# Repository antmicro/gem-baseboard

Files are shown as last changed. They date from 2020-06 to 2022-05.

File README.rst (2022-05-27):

GEM Demo Board
==============

Copyright (c) 2020 `Antmicro <https://www.antmicro.com>`_


   
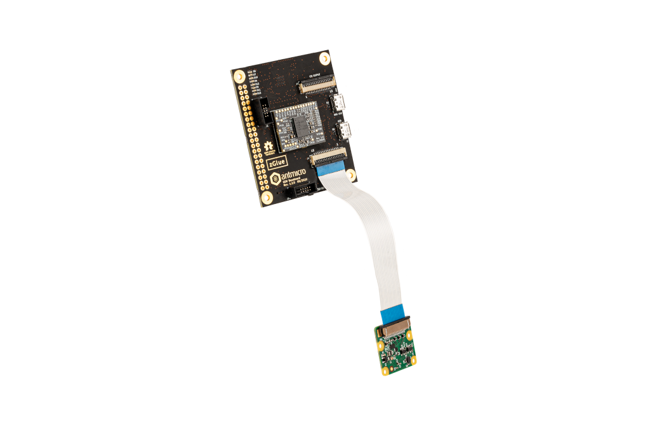
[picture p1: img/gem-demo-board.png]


This repository contains PCB design files for a demo board compatible with the `GEM1 <https://github.com/antmicro/gem1-adapter>`_ and `GEM2 <https://github.com/antmicro/gem2-adapter>`_ adapter boards.

The board acts as an evaluation carrier board for the GEM adapter boards.
It includes a 4-channel FTDI USB/MPSSE converter that can be used for configuring the chiplets inside the GEM designs from an external host PC using a single USB connection and the MPSSE engine built into the FTDI controller.

The board contains two FFC connectors supporting MIPI CSI input and output.
The FFC connectors are pin-compatible with the Raspberry Pi camera interface.
It is possible to connect a Raspberry Pi camera module to the input connector on the board and provide processed CSI data back on the output CSI FFC.
It is also possible to configure the board as an expansion hat for the Raspberry Pi platform.
For more details regarding the supported connection scenarios please refer to the respective schematic sheets.

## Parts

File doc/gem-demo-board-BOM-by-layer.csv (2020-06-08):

Reference | Quantity | Value | Footprint | Manufacturer | MPN | Layer
D10 D11 D12 D13 D6 D7 D8 D9 | 8 | LG_L29K-G2J1-24-Z | LED_0603 | OSRAM Opto Semiconductors Inc. | LG L29K-G2J1-24-Z | Top
D2 D5 | 2 | TPD2EUSB30DRTR | SOT-3 | Texas Instruments | TPD2EUSB30DRTR | Top
J1 J3 | 2 | 3220-10-0100-00 | PinHeader_2x5_P1.27mm_Drill.7mm | CNC Tech | 3220-10-0100-00 | Top
J10 J5 | 2 | 0473460001 | USB_Micro_B_Female_0473460001 | Molex | 0473460001 | Top
J6 J7 | 2 | 556500488 | 556500488 | Molex | 556500488 | Top
J8 J9 | 2 | WE_686115148922_FLIPPED | WE_686115148922_FLIPPED | Wurth Elektronik | 686115148922 | Top
C1 C2 C3 C4 C5 | 5 | C_1u_0603 | 0603-cap | WALSIN | 0603X105K160CT | Bottom
C10 C11 C12 C13 C14 C15 C16 C17 C18 C19 C20 C21 C22 C23 C24 C9 | 16 | C_100n_0402_6V3 | 0402-cap | Walsin | 0402X104K6R3CT | Bottom
C25 C26 | 2 | C_4u7_0402 | 0402-cap | MURATA | GRM155R60G475ME | Bottom
D1 D3 D4 | 3 | MBR0540T1G | SOD-123 | ON Semiconductor | MBR0540T1G | Bottom
FB1 FB2 | 2 | BLM18AG601SN1D | 0603 | Murata Electronics North America | BLM18AG601SN1D | Bottom
J2 | 1 | DF13A-2P-1.25H | DF13A-2P-1.25H | Hirose | DF13A-2P-1.25H | Bottom
J4 | 1 | 2x20_Header_Female | PinHeader_2x40_P2.54_Drill1mm | MULTICOMP | 2214S-40SG-85 | Bottom
R1 | 1 | R_0R_0603 | 0603-res | BOURNS | CR0603-J/-000ELF | Bottom
R10 R5 | 2 | R_2k_0402 | 0402-res | VISHAY | CRCW04022K00FKED | Bottom
R11 R12 R13 R14 R15 R16 R17 R18 R19 R2 R20 R21 R22 R23 R24 R25 R26 R27 R28 R29 R3 R30 R31 R32 R33 R42 R43 R48 R49 R58 R59 R60 R8 | 33 | R_0R_0402 | 0402-res | PANASONIC | ERJ2GE0R00X | Bottom
R34 | 1 | R_470R_0402 | 0402-res | VISHAY | CRCW0402470RFKED. | Bottom
R35 R36 R37 R38 R39 R40 R41 | 7 | R_330R_0402 | 0402-res | MULTICOMP | MCMR04X3300FTL | Bottom
R4 R6 R7 | 3 | R_10k_0402 | 0402-res | VISHAY | CRCW040210K0FKEDHP | Bottom
R61 | 1 | R_220R_0402 | 0402-res | TE_CONNECTIVITY_/_NEOHM | CRG0402J220R | Bottom
R9 | 1 | R_12k_0402 | 0402-res | VISHAY | CRCW040212K0FKEDHP | Bottom
S1 | 1 | EVQPUA02K | Panasonic_EVQPUJ_EVQPUA | Panasonic | EVQPUA02K | Bottom
U1 | 1 | MCP1700T-3302E_TT | SOT-23-3 | Microchip Technology | MCP1700T-3302E/TT | Bottom
U2 U3 U4 | 3 | NTS0104BQ | QDHVQFN14 | NXP Semiconductors | NTS0104BQ | Bottom
U5 | 1 | 93LC56CT-IMC | DFN-8_2x3mm | Microchip | 93LC56CT-I/MC | Bottom
U6 | 1 | FT4232HQ | FT4232HQ | FTDI | FT4232HQ | Bottom
U7 U8 | 2 | NTB0104BQ | QDHVQFN14 | NXP Semiconductors | NTB0104BQ | Bottom
Y1 | 1 | ASFLMB-12.000MHZ-LC-T | ASFLMB | TXC | ASFLMB-12.000MHZ-LC-T | Bottom
R44 R45 R46 R47 R50 R51 R52 R53 R54 R55 R56 R57 | 12 | R_0R_0402 | 0402-res | PANASONIC | ERJ2GE0R00X | DNP
N2 | 1 | zglue_logo | zglue-logo |  |  | Virtual
N3 | 1 | oshw_logo | oshw-logo |  |  | Virtual
TP1 TP10 TP11 TP12 TP13 TP14 TP15 TP16 TP17 TP18 TP19 TP2 TP20 TP21 TP22 TP23 TP3 TP4 TP5 TP6 TP7 TP8 TP9 | 23 | TP_SMD1MM | Testpoint_smd_1mm |  |  | Virtual
VCCIO1 VCCIO2 VCCIO3 | 3 | Jumper_3_Open-Jumper |  |  |  | Virtual

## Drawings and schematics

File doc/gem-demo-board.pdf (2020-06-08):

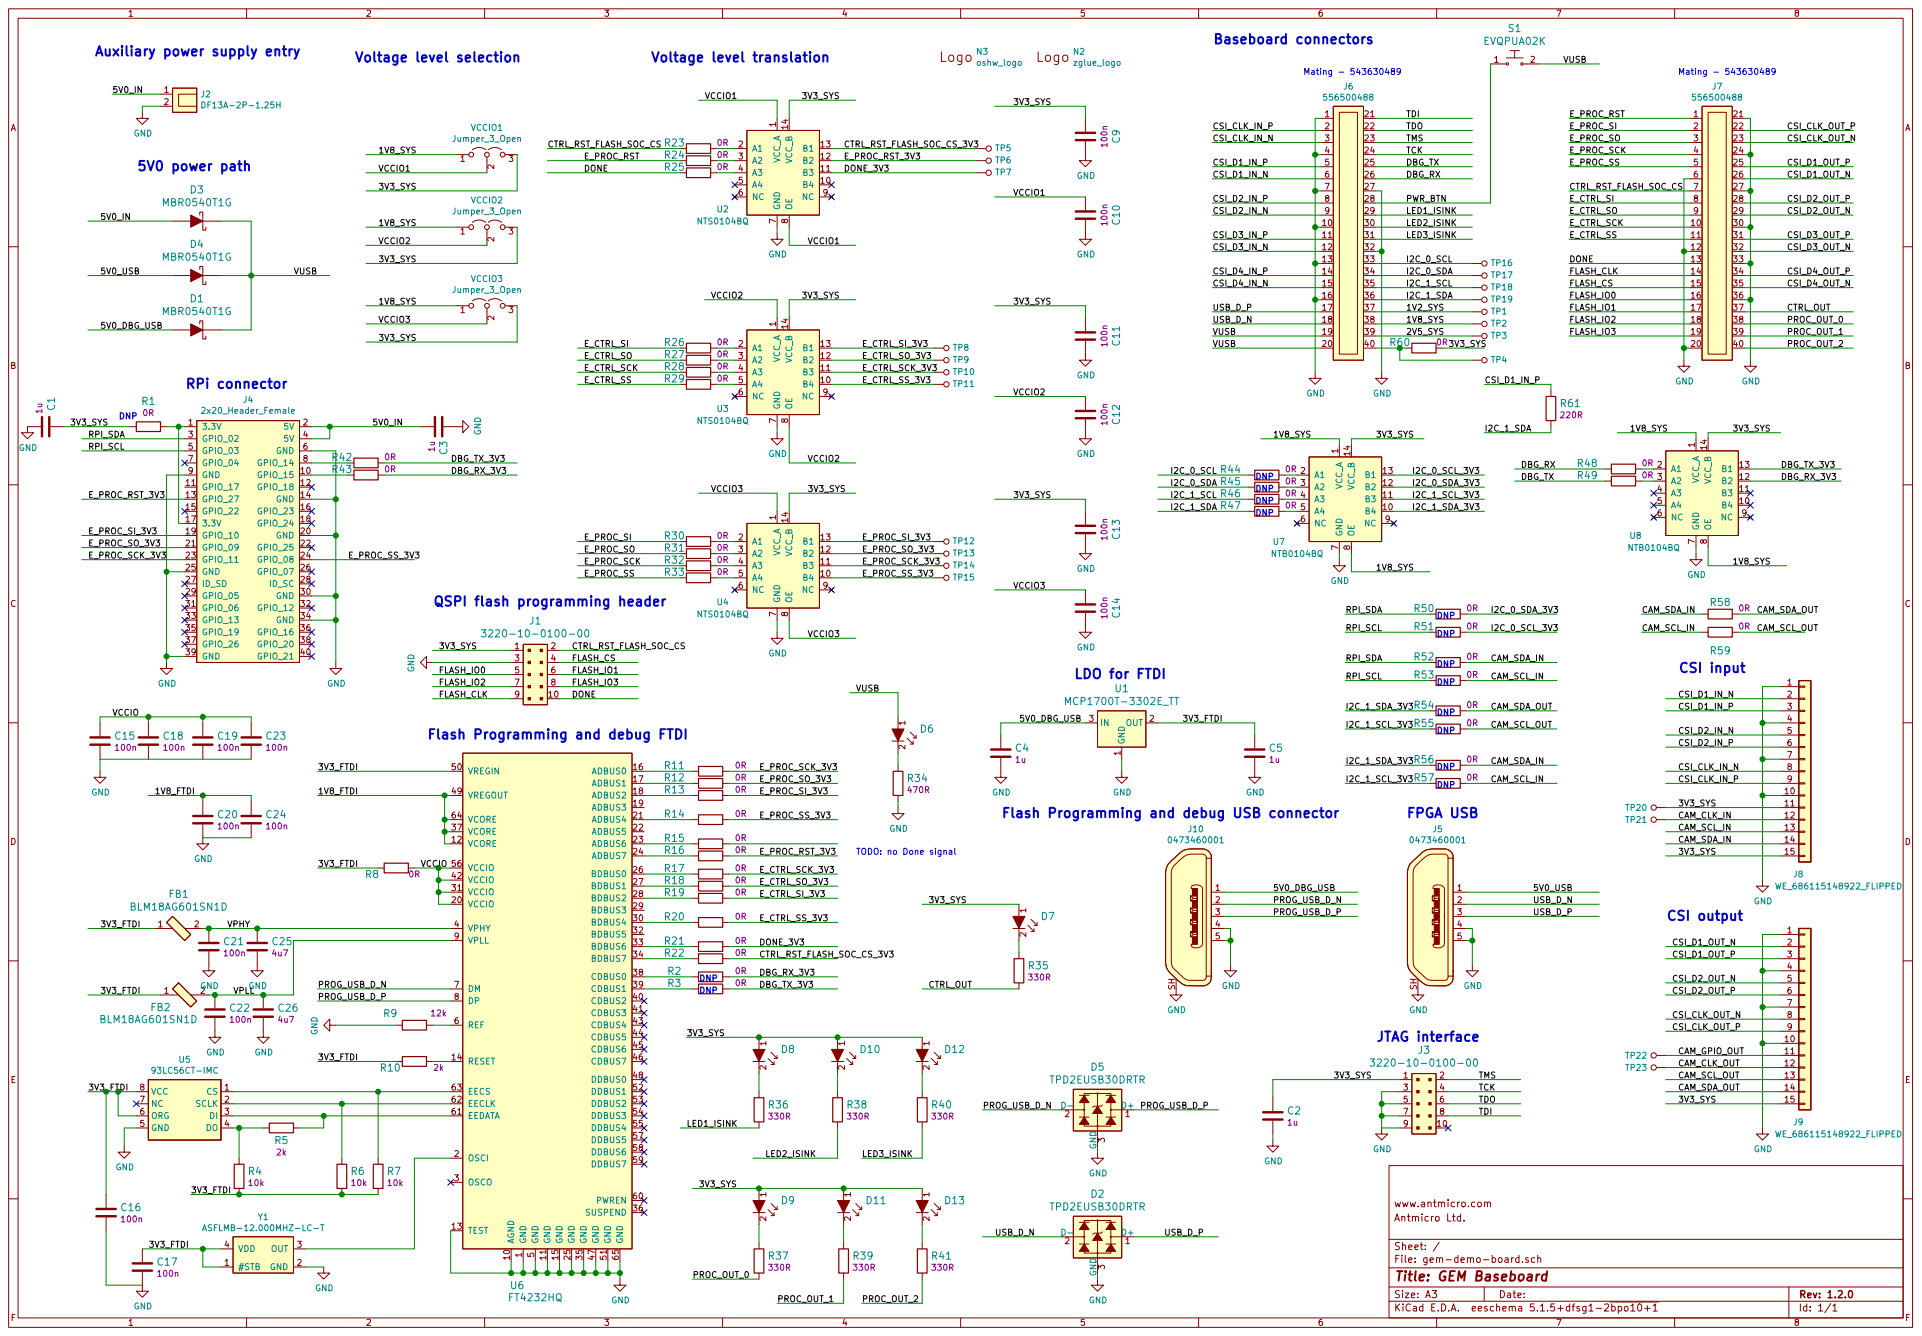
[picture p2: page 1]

Auxiliary power supply entry

23 TMS | E_PROC_SI CSI_D1_IN_N E_PROC_SO 3

22 TDO | 2

24 TCK | E_PROC_SCK 4
25 | E_PROC_SS 5
26 | 6

QSPI flash programming header

Flash Programming and debug FTDI

1 AGND 10 GND 11 VCORE 12 TEST 13 RESET 14 GND 15 ADBUS0 16 ADBUS1 17 ADBUS2 18 ADBUS3 19 OSCI 2 VCCIO 20 ADBUS4 21 ADBUS5 22 ADBUS6 23 ADBUS7 24 GND 25 BDBUS0 26 BDBUS1 27 BDBUS2 28 BDBUS3 29 OSCO 3 BDBUS4 30 VCCIO 31 BDBUS5 32 BDBUS6 33 BDBUS7 34 GND 35 SUSPEND 36 VCORE 37 CDBUS0 38 CDBUS1 39 VPHY 4 CDBUS2 40 CDBUS3 41 VCCIO 42 CDBUS4 43 CDBUS5 44 CDBUS6 45 CDBUS7 46 GND 47 DDBUS0 48 VREGOUT 49 GND

5 VREGIN 50 GND 51 DDBUS1 52 DDBUS2 53 DDBUS3 54 DDBUS4 55 VCCIO 56 DDBUS5 57 DDBUS6 58 DDBUS7 59 REF 6 PWREN 60 EEDATA 61 EECLK 62 EECS 63 VCORE 64 GND 65 DM 7 DP 8 VPLL 9 U6 FT4232HQ

Flash Programming and debug USB connector

TODO: no Done signal

File: gem-demo-board.sch Sheet: / Antmicro Ltd. www.antmicro.com

Id: 1/1 Title: GEM Baseboard

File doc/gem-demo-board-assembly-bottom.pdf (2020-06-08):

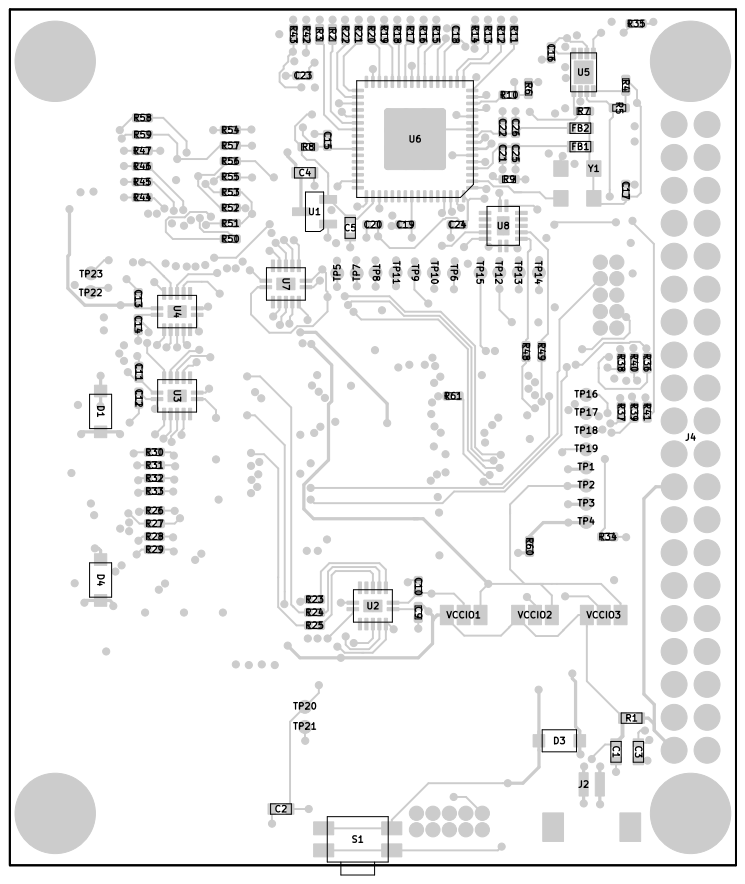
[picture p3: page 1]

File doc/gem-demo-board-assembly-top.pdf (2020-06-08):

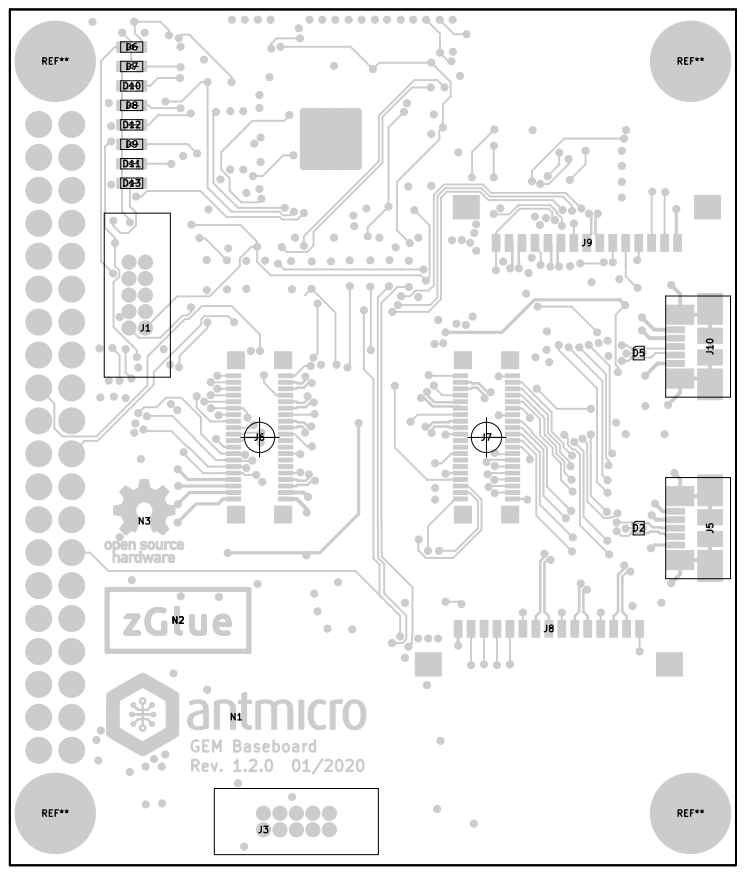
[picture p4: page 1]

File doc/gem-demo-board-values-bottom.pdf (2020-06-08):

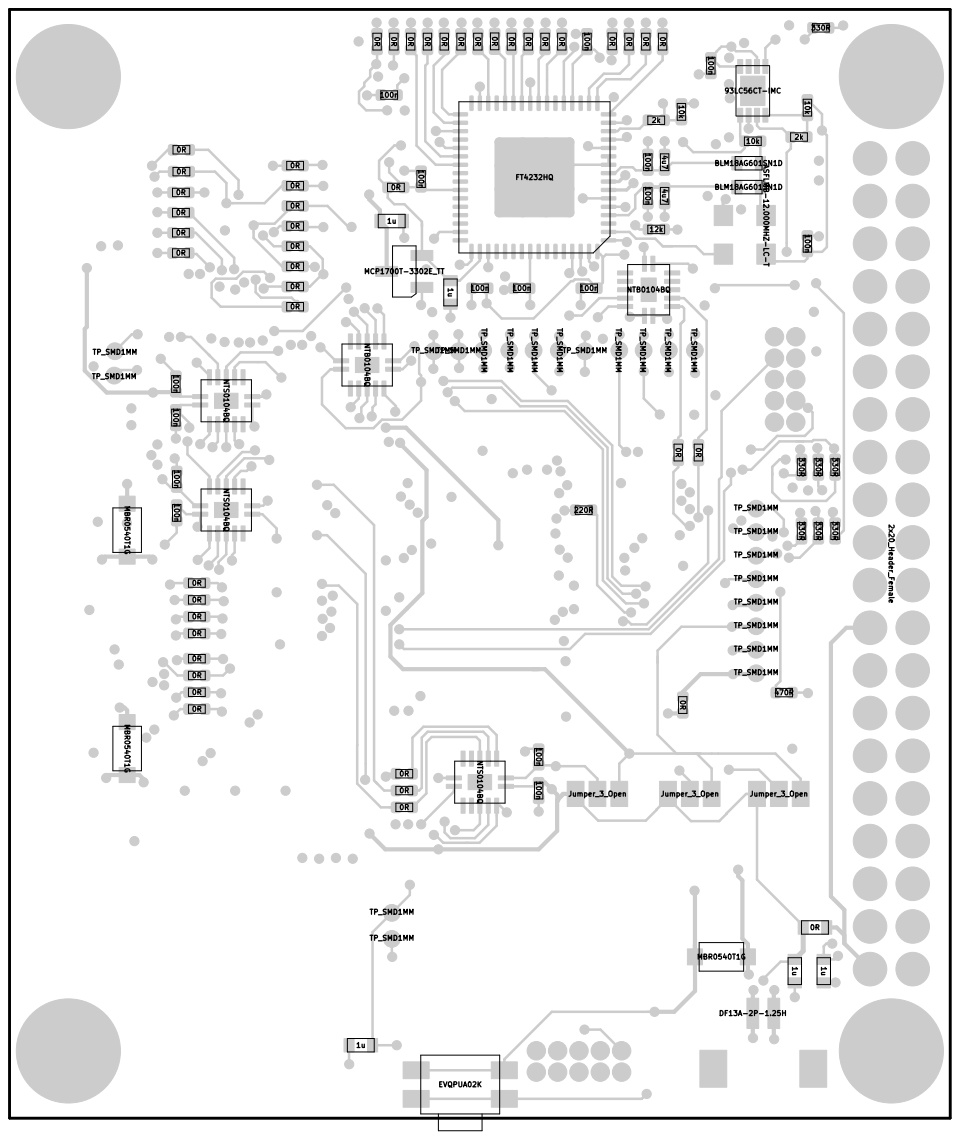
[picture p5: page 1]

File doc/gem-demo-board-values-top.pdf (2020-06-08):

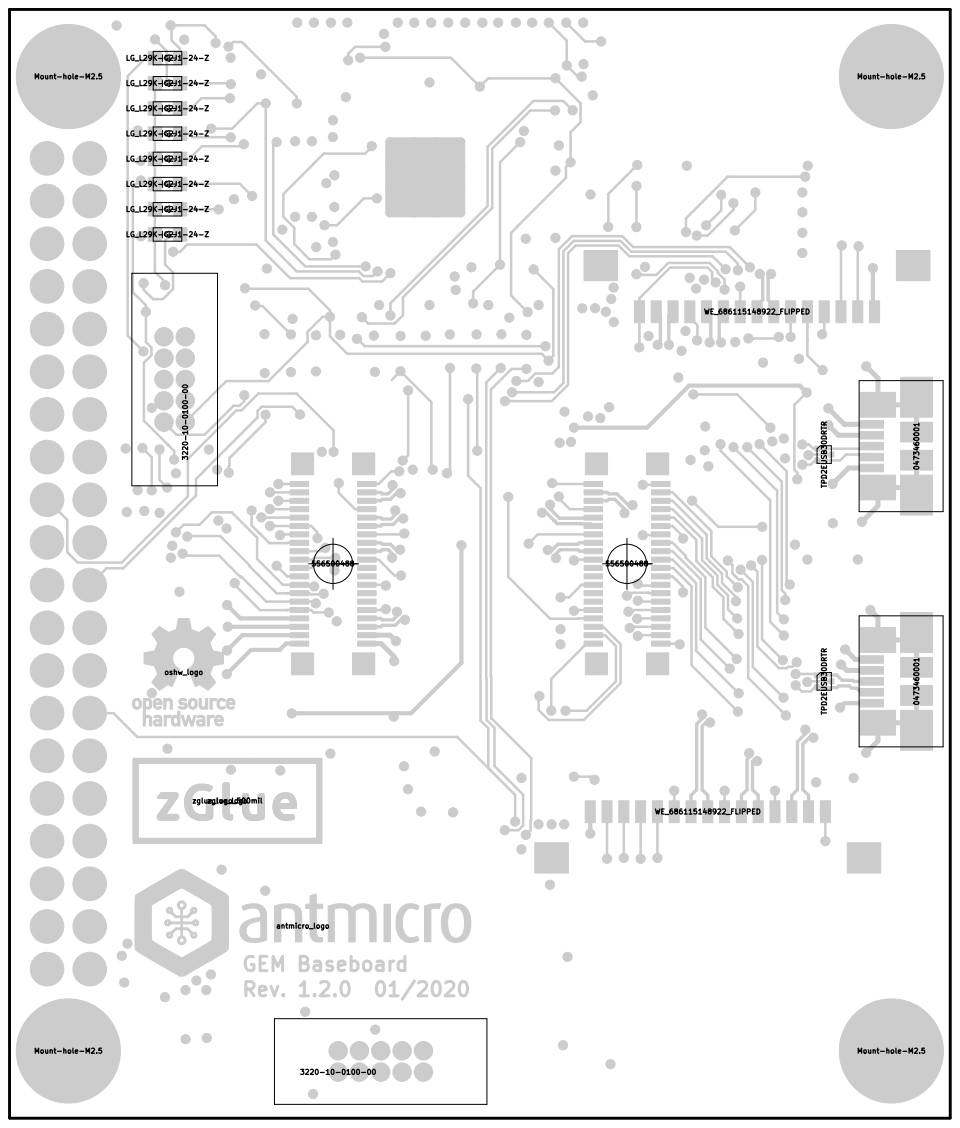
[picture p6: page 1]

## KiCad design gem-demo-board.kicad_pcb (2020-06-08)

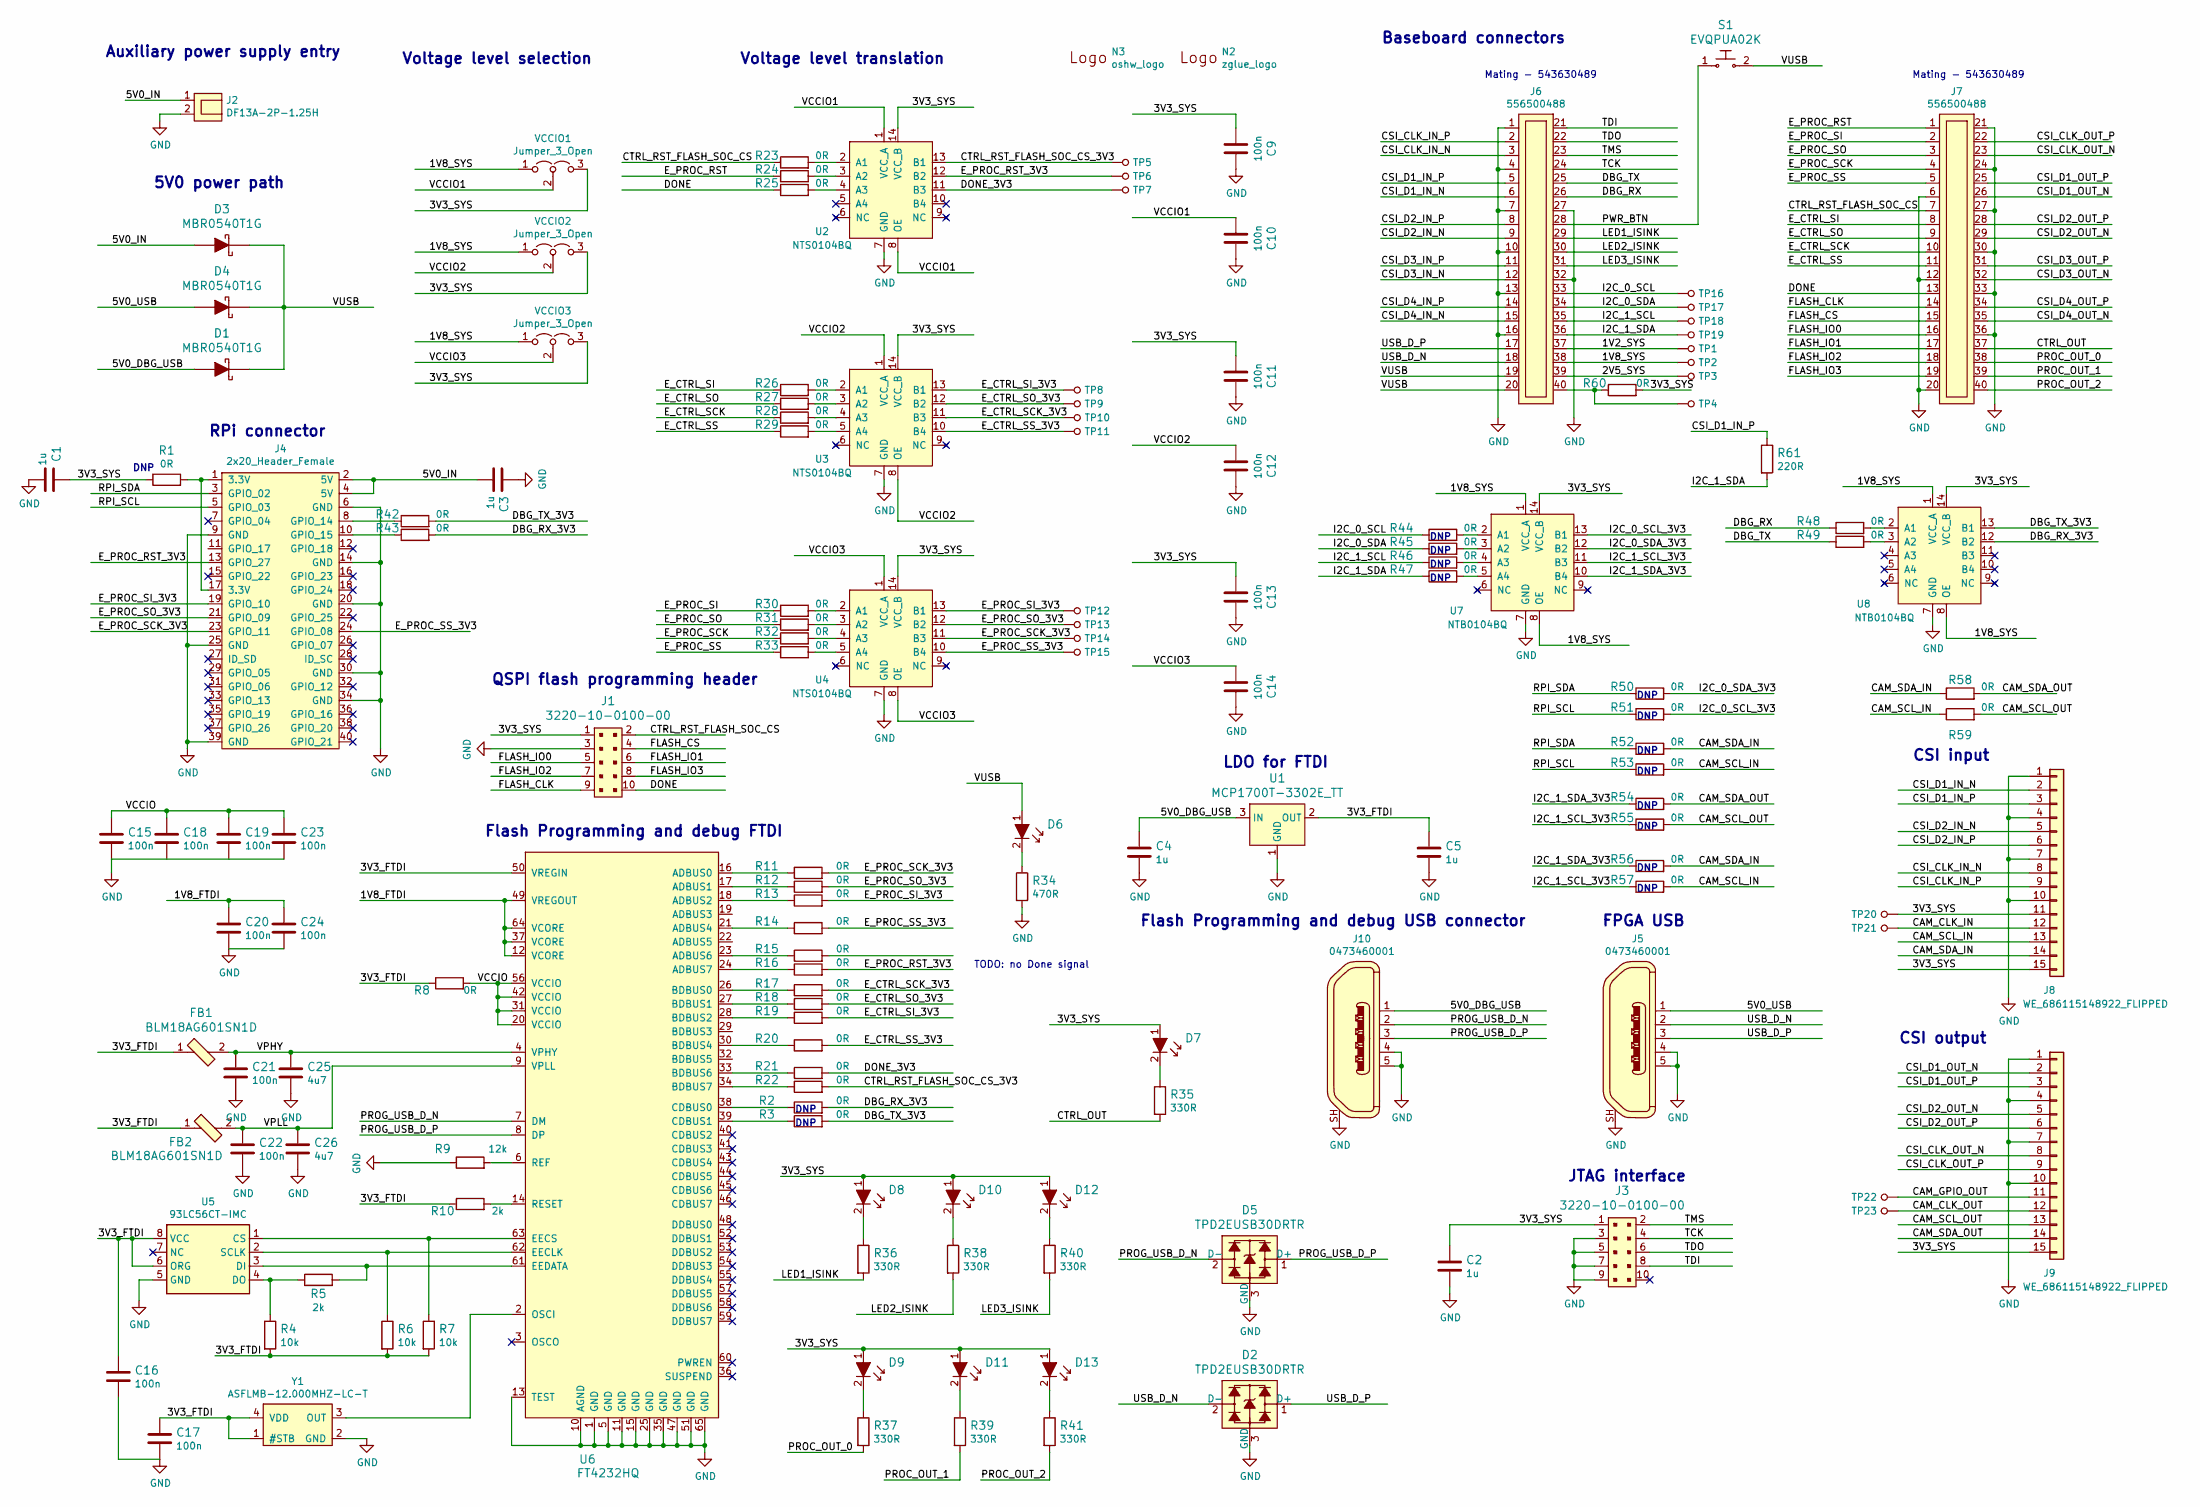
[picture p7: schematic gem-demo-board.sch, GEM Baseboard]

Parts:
C1, C2, C3, C4, C5: C_1u_0603; 0603-cap; MPN 0603X105K160CT
C9, C10, C11, C12, C13, C14, C15, C16, C17, C18, C19, C20, C21, C22, C23, C24: C_100n_0402_6V3; 0402-cap; MPN 0402X104K6R3CT
C25, C26: C_4u7_0402; 0402-cap; MPN GRM155R60G475ME
D1, D3, D4: MBR0540T1G; SOD-123; MPN MBR0540T1G
D2, D5: TPD2EUSB30DRTR; SOT-3; MPN TPD2EUSB30DRTR
D6, D7, D8, D9, D10, D11, D12, D13: LG_L29K-G2J1-24-Z; LED_0603; MPN LG L29K-G2J1-24-Z
FB1, FB2: BLM18AG601SN1D; 0603; MPN BLM18AG601SN1D
J1, J3: 3220-10-0100-00; PinHeader_2x5_P1.27mm_Drill.7mm; MPN 3220-10-0100-00
J2: DF13A-2P-1.25H; MPN DF13A-2P-1.25H
J4: 2x20_Header_Female; PinHeader_2x40_P2.54_Drill1mm; MPN 2214S-40SG-85
J5, J10: 0473460001; USB_Micro_B_Female_0473460001; MPN 0473460001
J6, J7: 556500488; MPN 556500488
J8, J9: WE_686115148922_FLIPPED; MPN 686115148922
N2: zglue_logo; zglue-logo
N3: oshw_logo; oshw-logo
R1: R_0R_0603; 0603-res; MPN CR0603-J/-000ELF
R2, R3, R8, R11, R12, R13, R14, R15, R16, R17, R18, R19, R20, R21, R22, R23, R24, R25, R26, R27, R28, R29, R30, R31, R32, R33, R42, R43, R44, R45, R46, R47, R48, R49, R50, R51, R52, R53, R54, R55, R56, R57, R58, R59, R60: R_0R_0402; 0402-res; MPN ERJ2GE0R00X
R4, R6, R7: R_10k_0402; 0402-res; MPN CRCW040210K0FKEDHP
R5, R10: R_2k_0402; 0402-res; MPN CRCW04022K00FKED
R9: R_12k_0402; 0402-res; MPN CRCW040212K0FKEDHP
R34: R_470R_0402; 0402-res; MPN CRCW0402470RFKED.
R35, R36, R37, R38, R39, R40, R41: R_330R_0402; 0402-res; MPN MCMR04X3300FTL
R61: R_220R_0402; 0402-res; MPN CRG0402J220R
S1: EVQPUA02K; Panasonic_EVQPUJ_EVQPUA; MPN EVQPUA02K
TP1, TP2, TP3, TP4, TP5, TP6, TP7, TP8, TP9, TP10, TP11, TP12, TP13, TP14, TP15, TP16, TP17, TP18, TP19, TP20, TP21, TP22, TP23: TP_SMD1MM; Testpoint_smd_1mm
U1: MCP1700T-3302E_TT; SOT-23-3; MPN MCP1700T-3302E/TT
U2, U3, U4: NTS0104BQ; QDHVQFN14; MPN NTS0104BQ
U5: 93LC56CT-IMC; DFN-8_2x3mm; MPN 93LC56CT-I/MC
U6: FT4232HQ; MPN FT4232HQ
U7, U8: NTB0104BQ; QDHVQFN14; MPN NTB0104BQ
VCCIO1, VCCIO2, VCCIO3: Jumper_3_Open; SolderJumper-3_P1.3mm_Open_Pad1.0x1.5mm
Y1: ASFLMB-12.000MHZ-LC-T; ASFLMB; MPN ASFLMB-12.000MHZ-LC-T

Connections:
/1V2_SYS: J6.37, TP1.1
/1V8_FTDI: C20.1, C24.1, U6.12 (VCORE), U6.37 (VCORE), U6.49 (VREGOUT), U6.64 (VCORE)
/1V8_SYS: J6.38, TP2.1, U7.1 (VCC_A), U7.8 (OE), U8.1 (VCC_A), U8.8 (OE), VCCIO1.1 (A), VCCIO2.1 (A), VCCIO3.1 (A)
/2V5_SYS: J6.39, TP3.1
/3V3_FTDI: C5.1, C16.1, C17.1, FB1.1, FB2.1, R4.2, R6.2, R7.2, R8.1, R10.1, U1.2 (OUT), U5.6 (ORG), U5.8 (VCC), U6.50 (VREGIN), Y1.1 (#STB), Y1.4 (VDD)
/3V3_SYS: C1.1, C2.1, C9.2, C11.2, C13.2, D7.1, D8.1, D9.1, D10.1, D11.1, D12.1, D13.1, J1.1, J3.1, J8.11, J8.15, J9.15, R1.1, R60.2, TP20.1, U2.14 (VCC_B), U3.14 (VCC_B), U4.14 (VCC_B), U7.14 (VCC_B), U8.14 (VCC_B), VCCIO1.3 (B), VCCIO2.3 (B), VCCIO3.3 (B)
/5V0_DBG_USB: C4.1, D1.A, J10.1, U1.3 (IN)
/5V0_IN: C3.2, D3.A, J2.1, J4.2 (5V), J4.4 (5V)
/5V0_USB: D4.A, J5.1
/CAM_CLK_IN: J8.12, TP21.1
/CAM_CLK_OUT: J9.12, TP23.1
/CAM_GPIO_OUT: J9.11, TP22.1
/CAM_SCL_IN: J8.13, R53.2, R57.2, R59.1
/CAM_SCL_OUT: J9.13, R55.2, R59.2
/CAM_SDA_IN: J8.14, R52.2, R56.2, R58.1
/CAM_SDA_OUT: J9.14, R54.2, R58.2
/CSI_CLK_IN_N: J6.3, J8.8
/CSI_CLK_IN_P: J6.2, J8.9
/CSI_CLK_OUT_N: J7.23, J9.8
/CSI_CLK_OUT_P: J7.22, J9.9
/CSI_D1_IN_N: J6.6, J8.2
/CSI_D1_IN_P: J6.5, J8.3, R61.1
/CSI_D1_OUT_N: J7.26, J9.2
/CSI_D1_OUT_P: J7.25, J9.3
/CSI_D2_IN_N: J6.9, J8.5
/CSI_D2_IN_P: J6.8, J8.6
/CSI_D2_OUT_N: J7.29, J9.5
/CSI_D2_OUT_P: J7.28, J9.6
/CSI_D3_IN_N: J6.12
/CSI_D3_IN_P: J6.11
/CSI_D3_OUT_N: J7.32
/CSI_D3_OUT_P: J7.31
/CSI_D4_IN_N: J6.15
/CSI_D4_IN_P: J6.14
/CSI_D4_OUT_N: J7.35
/CSI_D4_OUT_P: J7.34
/CTRL_OUT: J7.37, R35.2
/CTRL_RST_FLASH_SOC_CS: J1.2, J7.7, R23.1
/CTRL_RST_FLASH_SOC_CS_3V3: R22.2, TP5.1, U2.13 (B1)
/DBG_RX: J6.26, R48.1
/DBG_RX_3V3: R2.2, R43.2, U8.12 (B2)
/DBG_TX: J6.25, R49.1
/DBG_TX_3V3: R3.2, R42.2, U8.13 (B1)
/DONE: J1.10, J7.13, R25.1
/DONE_3V3: R21.2, TP7.1, U2.11 (B3)
/E_CTRL_SCK: J7.10, R28.1
/E_CTRL_SCK_3V3: R17.2, TP10.1, U3.11 (B3)
/E_CTRL_SI: J7.8, R26.1
/E_CTRL_SI_3V3: R19.2, TP8.1, U3.13 (B1)
/E_CTRL_SO: J7.9, R27.1
/E_CTRL_SO_3V3: R18.2, TP9.1, U3.12 (B2)
/E_CTRL_SS: J7.11, R29.1
/E_CTRL_SS_3V3: R20.2, TP11.1, U3.10 (B4)
/E_PROC_RST: J7.1, R24.1
/E_PROC_RST_3V3: J4.13 (GPIO_27), R16.2, TP6.1, U2.12 (B2)
/E_PROC_SCK: J7.4, R32.1
/E_PROC_SCK_3V3: J4.23 (GPIO_11), R11.2, TP14.1, U4.11 (B3)
/E_PROC_SI: J7.2, R30.1
/E_PROC_SI_3V3: J4.19 (GPIO_10), R13.2, TP12.1, U4.13 (B1)
/E_PROC_SO: J7.3, R31.1
/E_PROC_SO_3V3: J4.21 (GPIO_09), R12.2, TP13.1, U4.12 (B2)
/E_PROC_SS: J7.5, R33.1
/E_PROC_SS_3V3: J4.24 (GPIO_08), R14.2, TP15.1, U4.10 (B4)
/FLASH_CLK: J1.9, J7.14
/FLASH_CS: J1.4, J7.15
/FLASH_IO0: J1.5, J7.16
/FLASH_IO1: J1.6, J7.17
/FLASH_IO2: J1.7, J7.18
/FLASH_IO3: J1.8, J7.19
/I2C_0_SCL: J6.33, R44.1, TP16.1
/I2C_0_SCL_3V3: R51.2, U7.13 (B1)
/I2C_0_SDA: J6.34, R45.1, TP17.1
/I2C_0_SDA_3V3: R50.2, U7.12 (B2)
/I2C_1_SCL: J6.35, R46.1, TP18.1
/I2C_1_SCL_3V3: R55.1, R57.1, U7.11 (B3)
/I2C_1_SDA: J6.36, R47.1, R61.2, TP19.1
/I2C_1_SDA_3V3: R54.1, R56.1, U7.10 (B4)
/LED1_ISINK: J6.29, R36.2
/LED2_ISINK: J6.30, R38.2
/LED3_ISINK: J6.31, R40.2
/PROC_OUT_0: J7.38, R37.2
/PROC_OUT_1: J7.39, R39.2
/PROC_OUT_2: J7.40, R41.2
/PROG_USB_D_N: D5.2 (D-), J10.2, U6.7 (DM)
/PROG_USB_D_P: D5.1 (D+), J10.3, U6.8 (DP)
/PWR_BTN: J6.28, S1.1
/RPI_SCL: J4.5 (GPIO_03), R51.1, R53.1
/RPI_SDA: J4.3 (GPIO_02), R50.1, R52.1
/TCK: J3.4, J6.24
/TDI: J3.8, J6.21
/TDO: J3.6, J6.22
/TMS: J3.2, J6.23
/USB_D_N: D2.2 (D-), J5.2, J6.18
/USB_D_P: D2.1 (D+), J5.3, J6.17
/VCCIO: C15.1, C18.1, C19.1, C23.1, R8.2, U6.20 (VCCIO), U6.31 (VCCIO), U6.42 (VCCIO), U6.56 (VCCIO)
/VCCIO1: C10.2, U2.1 (VCC_A), U2.8 (OE), VCCIO1.2 (C)
/VCCIO2: C12.2, U3.1 (VCC_A), U3.8 (OE), VCCIO2.2 (C)
/VCCIO3: C14.2, U4.1 (VCC_A), U4.8 (OE), VCCIO3.2 (C)
/VPHY: C21.1, C25.1, FB1.2, U6.4 (VPHY)
/VPLL: C22.1, C26.1, FB2.2, U6.9 (VPLL)
/VUSB: D1.K, D3.K, D4.K, D6.1, J6.19, J6.20, S1.2
GND: C1.2, C2.2, C3.1, C4.2, C5.2, C9.1, C10.1, C11.1, C12.1, C13.1, C14.1, C15.2, C16.2, C17.2, C20.2, C21.2, C22.2, C23.2, C24.2, C25.2, C26.2, D2.3 (GND), D5.3 (GND), J1.3, J2.2, J3.3, J3.5, J3.7, J3.9, J4.6 (GND), J4.9 (GND), J4.14 (GND), J4.20 (GND), J4.25 (GND), J4.30 (GND), J4.34 (GND), J4.39 (GND), J5.4, J5.5, J5.SH, J6.1, J6.4, J6.7, J6.10, J6.13, J6.16, J6.27, J6.32, J7.6, J7.12, J7.20, J7.21, J7.24, J7.27, J7.30, J7.33, J7.36, J8.1, J8.4, J8.7, J8.10, J9.1, J9.4, J9.7, J9.10, J10.4, J10.5, J10.SH, R9.1, R34.2, U1.1 (GND), U2.7 (GND), U3.7 (GND), U4.7 (GND), U5.5 (GND), U6.1 (GND), U6.5 (GND), U6.10 (AGND), U6.11 (GND), U6.13 (TEST), U6.15 (GND), U6.25 (GND), U6.35 (GND), U6.47 (GND), U6.51 (GND), U6.65 (GND), U7.7 (GND), U8.7 (GND), Y1.2 (GND)
unnamed: D6.2, R34.1
unnamed: D7.2, R35.1
unnamed: D8.2, R36.1
unnamed: D9.2, R37.1
unnamed: D10.2, R38.1
unnamed: D11.2, R39.1
unnamed: D12.2, R40.1
unnamed: D13.2, R41.1
unnamed: J4.1 (3.3V), J4.17 (3.3V), R1.2
unnamed: J4.8 (GPIO_14), R42.1
unnamed: J4.10 (GPIO_15), R43.1
unnamed: J6.40, R60.1, TP4.1
unnamed: R2.1, U6.38 (CDBUS0)
unnamed: R3.1, U6.39 (CDBUS1)
unnamed: R4.1, R5.1, U5.4 (DO)
unnamed: R5.2, U5.3 (DI), U6.61 (EEDATA)
unnamed: R6.1, U5.2 (SCLK), U6.62 (EECLK)
unnamed: R7.1, U5.1 (CS), U6.63 (EECS)
unnamed: R9.2, U6.6 (REF)
unnamed: R10.2, U6.14 (RESET)
unnamed: R11.1, U6.16 (ADBUS0)
unnamed: R12.1, U6.17 (ADBUS1)
unnamed: R13.1, U6.18 (ADBUS2)
unnamed: R14.1, U6.21 (ADBUS4)
unnamed: R15.1, U6.23 (ADBUS6)
unnamed: R16.1, U6.24 (ADBUS7)
unnamed: R17.1, U6.26 (BDBUS0)
unnamed: R18.1, U6.27 (BDBUS1)
unnamed: R19.1, U6.28 (BDBUS2)
unnamed: R20.1, U6.30 (BDBUS4)
unnamed: R21.1, U6.33 (BDBUS6)
unnamed: R22.1, U6.34 (BDBUS7)
unnamed: R23.2, U2.2 (A1)
unnamed: R24.2, U2.3 (A2)
unnamed: R25.2, U2.4 (A3)
unnamed: R26.2, U3.2 (A1)
unnamed: R27.2, U3.3 (A2)
unnamed: R28.2, U3.4 (A3)
unnamed: R29.2, U3.5 (A4)
unnamed: R30.2, U4.2 (A1)
unnamed: R31.2, U4.3 (A2)
unnamed: R32.2, U4.4 (A3)
unnamed: R33.2, U4.5 (A4)
unnamed: R44.2, U7.2 (A1)
unnamed: R45.2, U7.3 (A2)
unnamed: R46.2, U7.4 (A3)
unnamed: R47.2, U7.5 (A4)
unnamed: R48.2, U8.2 (A1)
unnamed: R49.2, U8.3 (A2)
unnamed: U6.2 (OSCI), Y1.3 (OUT)

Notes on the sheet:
Baseboard connectors
Auxiliary power supply entry
RPi connector
JTAG interface
FPGA USB
5V0 power path
CSI input
CSI output
Mating - 543630489
Voltage level translation
Flash Programming and debug USB connector
Flash Programming and debug FTDI
TODO: no Done signal
LDO for FTDI
Voltage level selection
QSPI flash programming header
DNP

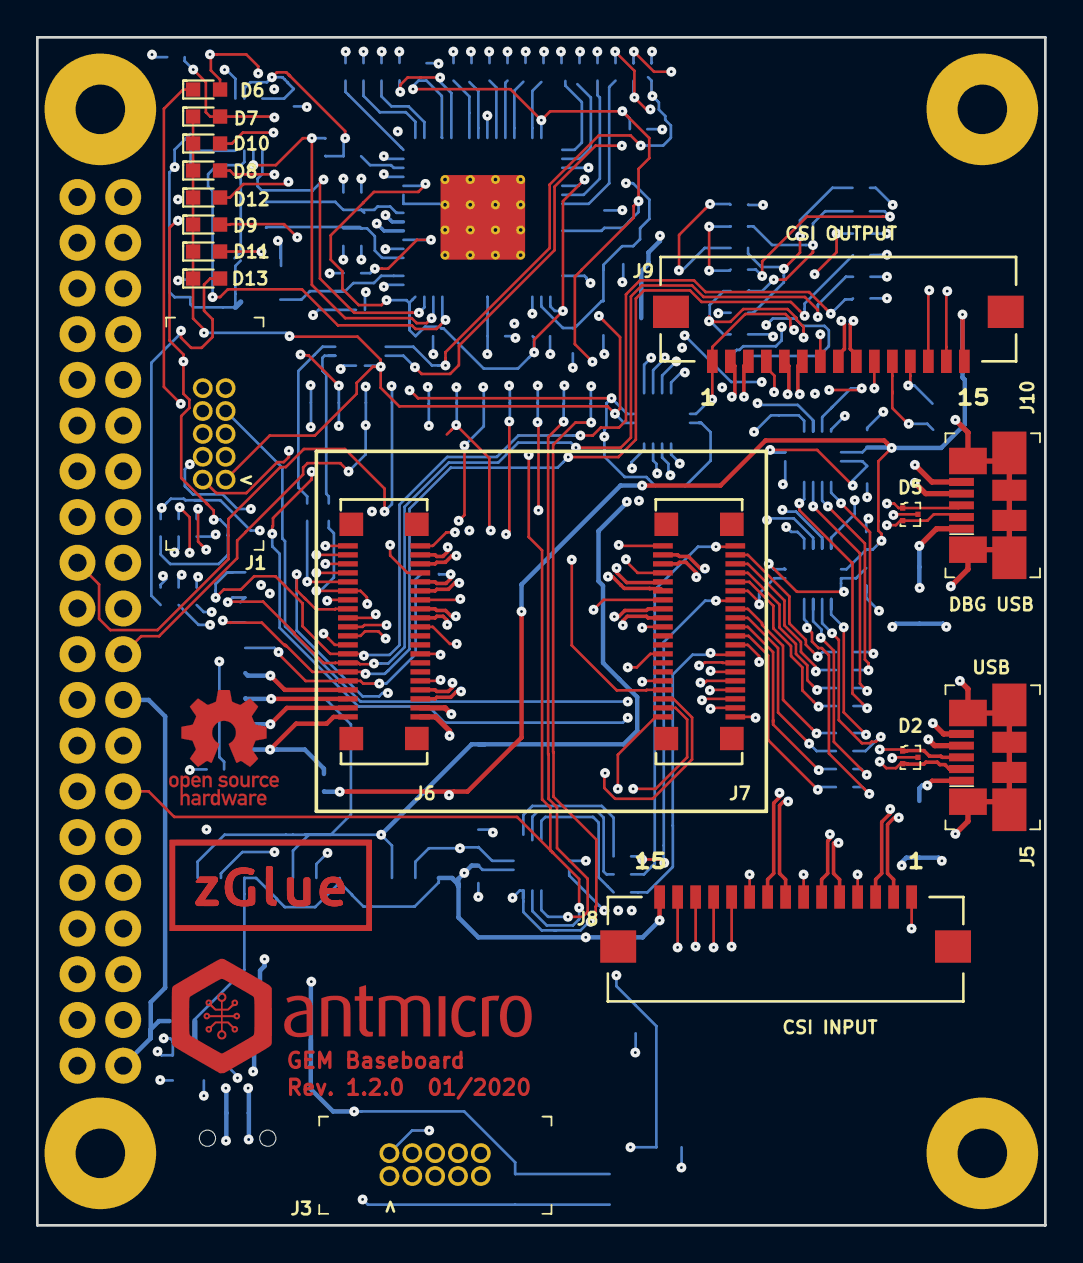
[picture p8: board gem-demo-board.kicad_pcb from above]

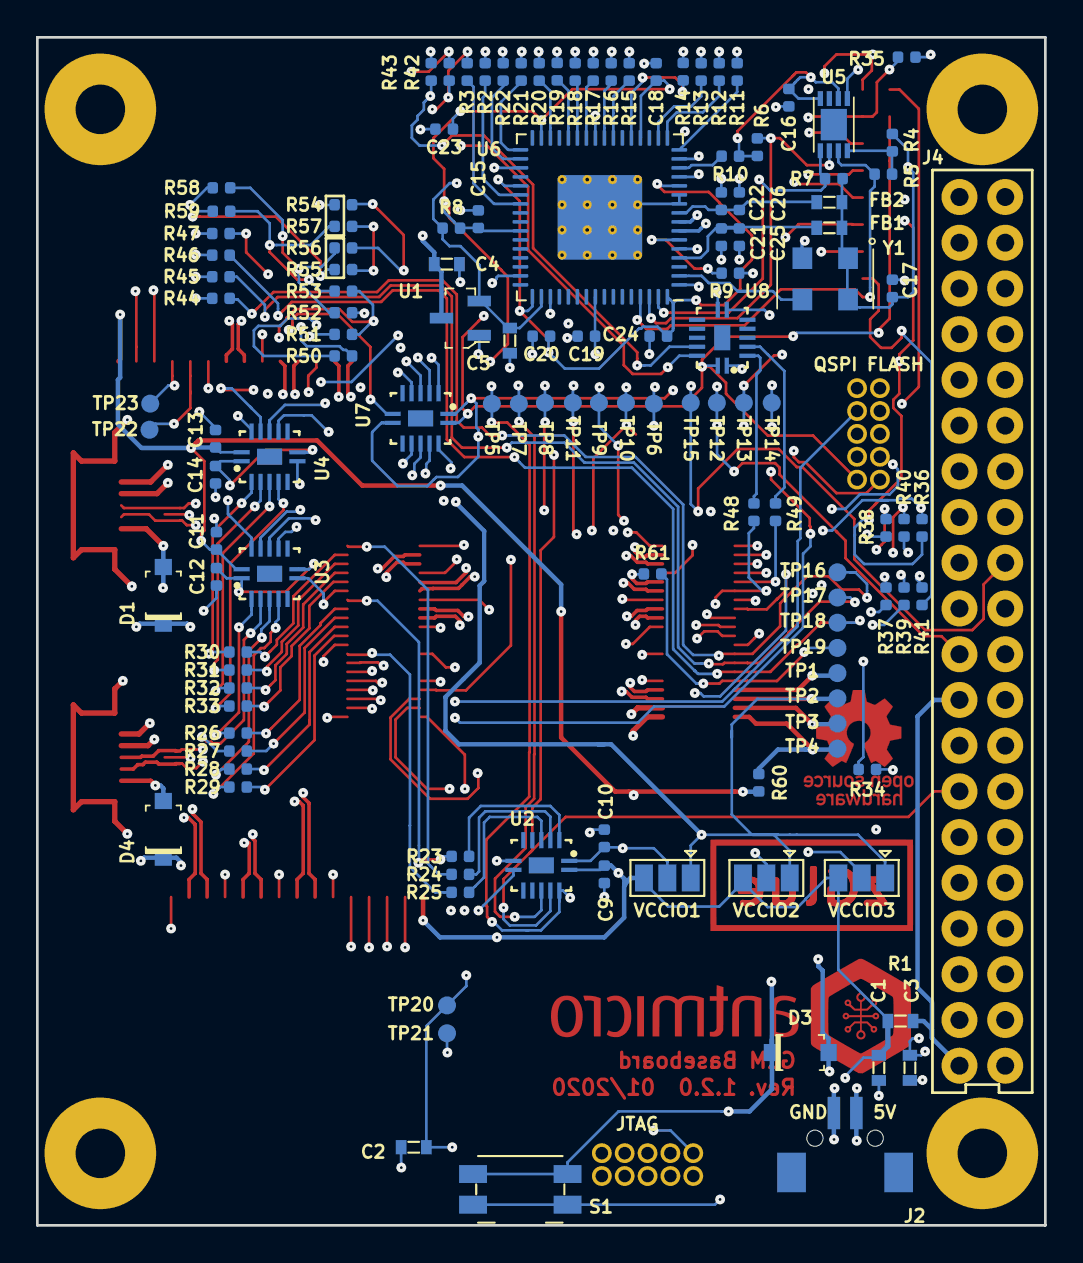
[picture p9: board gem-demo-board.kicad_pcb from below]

Board: 6 copper layers, 56.0 x 66.0 mm, 149 parts (127 on the bottom side), 144 nets.

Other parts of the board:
N1: antmicro_logo; antmicro-logo_scaled_20mm
N2#2: zglue_logo; zglue-logo

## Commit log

2020-02-19 Added FT4232
    [zglue-demo-board.kicad_pcb, zglue-demo-board.sch]
2020-02-19 Exported PDF schematic
2020-02-19 Fixed power path
    [zglue-demo-board.sch]
2020-02-19 Unified 3V3 voltage rails
    [zglue-demo-board.sch]
2020-02-19 Schematic cleanup
    [zglue-demo-board.sch]
2020-02-19 Finished initial component placement
    [zglue-demo-board.kicad_pcb, zglue-demo-board.sch]
2020-02-19 Generated schematic pdf
2020-02-19 Rotated adapter board footprint by 180 deg
    [zglue-demo-board.kicad_pcb]
2020-02-19 Finished routing
    [zglue-demo-board-B.Cu.gbr, zglue-demo-board-B.Mask.gbr, zglue-demo-board-B.Paste.gbr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]
2020-02-19 Tuned differential pairs
    [zglue-demo-board-B.Cu.gbr, zglue-demo-board-B.Mask.gbr, zglue-demo-board-B.Paste.gbr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]
2020-02-19 Added programming header for QSPI flash
    [zglue-demo-board-B.Cu.gbr, zglue-demo-board-B.Mask.gbr, zglue-demo-board-B.Paste.gbr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]
2020-02-19 Added LEDs and power button
    [zglue-demo-board-B.Cu.gbr, zglue-demo-board-B.Mask.gbr, zglue-demo-board-B.Paste.gbr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]
2020-02-19 Added mounting holes
    [zglue-demo-board-B.Cu.gbr, zglue-demo-board-B.Mask.gbr, zglue-demo-board-B.Paste.gbr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]
2020-02-19 Added connections for I2C and UART
    [zglue-demo-board-B.Cu.gbr, zglue-demo-board-B.Mask.gbr, zglue-demo-board-B.Paste.gbr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]
2020-02-19 Added BOM
    [zglue-demo-board.csv]
2020-02-19 Schematic updated after initial bringup
    [zglue-demo-board.kicad_pcb, zglue-demo-board.sch]
2020-02-19 Started revision 1.1, moved components to bottom side
    [zglue-demo-board.kicad_pcb, zglue-demo-board.sch]
2020-02-19 Routing finished
    [zglue-demo-board.kicad_pcb]
2020-02-19 Tied SPI signals for programming second FPGA from RPi
    [zglue-demo-board-B_Cu.gbr, zglue-demo-board-B_Mask.gbr, zglue-demo-board-B_Paste.gbr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]
2020-02-19 PCB cleanup, updated layout
    [zglue-demo-board-B.Cu.gbr, zglue-demo-board-B.Mask.gbr, zglue-demo-board-B.Paste.gbr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]
2020-02-19 Connected PWR_BTN to VUSB, updated PCB
    [zglue-demo-board-B_Cu.gbr, zglue-demo-board-B_Mask.gbr, zglue-demo-board-B_Paste.gbr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]
2020-02-19 Gerber files used for PCB manufacturing
    [zglue-demo-board-B_Cu.gbr, zglue-demo-board-B_Mask.gbr, zglue-demo-board-B_Paste.gbr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]
2020-02-19 Layout components moved away from PCB edges
    [zglue-demo-board-B_Cu.gbr, zglue-demo-board-B_Mask.gbr, zglue-demo-board-B_Paste.gbr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]
2020-02-19 Flipped CSI input connector
    Use camera FFC with pads on the same side now
    [gem-demo-board.kicad_pcb, gem-demo-board.sch]
2020-02-19 Minor changes
    [gem-demo-board.kicad_pcb, gem-demo-board.sch]
2020-02-19 Disconnected 3v3_sys from GEM system chip with R60
    [gem-demo-board.kicad_pcb, gem-demo-board.sch]
2020-02-19 Connect CSI_D1_IN_P to I2C_1_SDA through R61
    [gem-demo-board.kicad_pcb, gem-demo-board.sch]
2020-02-19 Exported R_220R to local library
    [gem-demo-board.kicad_pcb, gem-demo-board.sch]
2020-02-19 Updated rev. number and date
    [gem-demo-board.kicad_pcb]
2020-02-19 Cleanup of DRC issues
    [gem-demo-board.kicad_pcb, gem-demo-board.sch]
2020-02-19 Minor updates on PCB
    [gem-demo-board.kicad_pcb, gem-demo-board.sch]
2020-02-19 Moved JTAG connector
    [gem-demo-board-BOM-by-layer.csv, gem-demo-board-BOM-populated.csv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]
2020-06-08 Fixed MPN for 12Mhz oscillator
    [gem-demo-board.sch]
2020-06-08 Updated Project Name
    [gem-demo-board.sch]
2020-06-08 Updated revision marking
    [gem-demo-board.kicad_pcb, gem-demo-board.sch]
2020-06-08 Add documentation for release
    [gem-demo-board-BOM-by-layer.csv, gem-demo-board-BOM-populated.csv]
